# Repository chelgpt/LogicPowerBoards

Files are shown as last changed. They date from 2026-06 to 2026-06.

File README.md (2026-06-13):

# LogicPowerBoards

KiCad/KiCanvas workspace for the Docreate 002 modernization boards.

This repository is prepared for browser-based review through GitHub Pages + KiCanvas.

## Boards

- PowerBoard: 24V input, 5V / 20A isolated DC-DC board based on Mornsun URF2405QB-100WR3.
- LogicBoard: 24V input, 12V / 6W isolated DC-DC board based on Mornsun URB2412ZP-6WR3.

## Viewer

After enabling GitHub Pages from `main` / `docs`, open:

- `https://chelgpt.github.io/LogicPowerBoards/power.html`
- `https://chelgpt.github.io/LogicPowerBoards/logic.html`

Status: initial AI-assisted clean starter, not yet production-approved. Final manufacturing requires datasheet pinout verification, ERC/DRC, Gerber review, and ideally human EE review.

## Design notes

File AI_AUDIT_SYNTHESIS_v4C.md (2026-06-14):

# AI audit synthesis v4C

## Adopted facts

1. PowerBoard URF pin map: 1 +Vin, 2 Ctrl, 3 -Vin, 4 0V, 5 Sense-, 6 Trim, 7 Sense+, 8 +Vo.
2. PowerBoard URF drill sizes updated: 1.5mm for pins 1 2 3 5 6 7; 2.0mm for pins 4 8.
3. LogicBoard URB footprint changed from DIP8 placeholder to DIP24-grid footprint.
4. LogicBoard URB populated pins: 2 3 GND, 11 NC, 14 +Vo, 16 0V, 22 23 Vin.
5. LogicBoard capacitors updated to 100uF input bulk, 1uF input HF, 10uF output bulk, 100nF output HF.
6. PowerBoard precharge value is still TBD because it depends on C_bank, ESR, charge current and duty cycle.
7. PowerBoard TVS is now a selectable footprint, not a final installed value.
8. Output connector is marked as 30A-class target.
9. KiCad ERC, DRC, Gerber export and independent Gerber viewer check remain mandatory.

## Current verdict

LogicBoard is now a corrected v4C engineering candidate. PowerBoard is mechanically corrected and architecturally improved, but requires precharge and thermal closure before fab release.

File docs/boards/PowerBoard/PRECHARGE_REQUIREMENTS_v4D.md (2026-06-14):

# PowerBoard precharge requirements v4D

## Hard fact

The PowerBoard is not allowed to connect a large capacitive bank directly to the 5V output as if it were a normal output capacitor.

## Required input data

Before finalizing R_LIMIT or bypass parts, collect:

- C_bank in farads.
- Bank ESR in ohms.
- Initial voltage range.
- Target voltage.
- Allowed charge current.
- Required charge time.
- Charge repetition rate.
- Ambient temperature.
- Airflow or heatsink conditions.
- Whether the bank remains connected during normal 20A load operation.

## Sizing equations

- Peak current through resistor: I_peak = V_source / (R_LIMIT + ESR_bank + ESR_path)
- Stored energy in bank: E_bank = 0.5 * C_bank * V_target^2
- Resistor initial power: P0 = I_peak^2 * R_LIMIT
- RC time constant: tau = R_LIMIT * C_bank
- Approximate voltage after time t: Vc = V_source * (1 - exp(-t / tau))

## Topology decision

For private prototype use, keep two modes:

1. Safe test mode: R_LIMIT installed, bypass open.
2. Normal mode: R_LIMIT precharges first, then relay or MOSFET bypass shorts R_LIMIT after voltage delta is small.

## PCB implication

- R_LIMIT footprint is only a placeholder until energy and pulse rating are selected.
- J_BYP is intended for external relay or MOSFET bypass wiring.
- Do not install permanent zero-ohm bypass for first power-up.
- Add a bench procedure label: precharge first, bypass second.

## Remaining decision

The PCB cannot be called final until C_bank and I_charge are known.

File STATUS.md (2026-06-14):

# Project status

## Current version

v4M BOM and production gate pass.

## What changed in v4K

- PowerBoard PCB includes M3 mounting holes.
- PowerBoard PCB includes testpoints: TP_VIN, TP_GNDIN, TP_5V, TP_0V, TP_TRIM, TP_S+, TP_S-.
- PowerBoard silkscreen includes stronger guards: no-copper-under-module, remote-sense warning, precharge-first warning, input/output labels.
- LogicBoard PCB includes M3 mounting holes.
- LogicBoard PCB includes testpoints: TP1_24V, TP2_GND, TP3_12V, TP4_0V.
- Validator requires v4K testpoints, mounting holes and board marks.
- Added FAB_READINESS_SCORECARD_v4K.md.

## What changed in v4L

- Added ENGINEERING_FREEZE_v4L.md.
- Stopped speculative layout churn until CI logs, generated Gerbers, official footprint coordinates or real PowerBoard load data are available.

## What changed in v4M

- Updated PowerBoard_BOM.csv to match the v4K PCB state and current engineering decisions.
- Updated LogicBoard_BOM.csv to match the v4K PCB state and reject the stale DIP8 assumption.
- Added BOM_AUDIT_v4M.md to reconcile the uploaded BOM/TZ with the current design.
- Added ASSEMBLY_AND_BRINGUP_v4M.md.
- Added PRODUCTION_GATE_v4M.md.
- Fixed validate_repo.py version matcher so v4L/v4M and later statuses do not break CI.

## Current confidence

- LogicBoard: 89/100 as PCB architecture before automated ERC/DRC. Close to private prototype candidate after clean ERC/DRC and footprint-coordinate check.
- PowerBoard: 78/100 as PCB architecture before automated ERC/DRC and precharge closure. Not blind-order production-ready until real capacitive-bank/precharge data are closed.

## Next objective

Continue toward validation output, not cosmetic layout churn:

1. Get text-validation to pass.
2. Run or inspect heavy KiCad ERC/DRC/Gerber workflow.
3. Fix actual reported errors.
4. Produce reviewed fabrication package.

## Hard warning

v4M improves BOM/assembly/readiness closure but is still not a production release. The remaining blockers are validation outputs and PowerBoard load/precharge data.

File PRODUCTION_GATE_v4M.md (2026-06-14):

# Production gate v4M

## Gate result today

- LogicBoard: engineering prototype candidate, not final production release until ERC/DRC/Gerber pass.
- PowerBoard: engineering candidate, blocked by supercap/precharge/load data and ERC/DRC/Gerber pass.

## What can be considered ready

The repository is ready for automated validation and fabrication package generation attempts.

## What is not ready

The repository is not ready for blind PCB factory order.

## LogicBoard release path

LogicBoard can move to private prototype order after all of the following are true:

1. Text validation passes.
2. KiCad ERC passes.
3. KiCad DRC passes.
4. Gerber and drill files are generated.
5. Gerbers are reviewed.
6. Official URB2412ZP-6WR3 footprint coordinates are checked.

## PowerBoard release path

PowerBoard can move to private prototype order after all LogicBoard-style fabrication gates plus:

1. Real C_bank is known.
2. Real bank ESR is known.
3. Allowed charge current is known.
4. R_LIMIT value and pulse rating are selected.
5. Bypass relay/MOSFET strategy is selected.
6. Output connector part number and current rating are selected.
7. Thermal behavior is acceptable in bench test.

## Decision matrix

| Condition | LogicBoard | PowerBoard |
|---|---:|---:|
| Schematic exists | yes | yes |
| PCB exists | yes | yes |
| BOM current | yes | yes |
| Testpoints | yes | yes |
| Mounting holes | yes | yes |
| Text validator | present | present |
| ERC result | pending | pending |
| DRC result | pending | pending |
| Gerbers | pending | pending |
| Official footprint coordinates | pending | pending |
| Load/precharge closure | not needed | pending |

## Final instruction

Do not call this production-ready until pending rows are closed.

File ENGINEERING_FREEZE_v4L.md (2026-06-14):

# Engineering freeze v4L

## Decision

The current repository state is frozen as an engineering candidate until automated validation results or real PowerBoard load data are available.

This is not a prompt for more speculative layout iterations. Further edits without CI feedback would increase churn and may reduce quality.

## Current board scores

- LogicBoard: 88/100 as PCB architecture before automated ERC/DRC.
- PowerBoard: 76/100 as PCB architecture before automated ERC/DRC and precharge closure.

## What is already closed

- Browser KiCanvas review workflow.
- Main page with board tabs and engineering document links.
- PowerBoard and LogicBoard PCB text files.
- Component-level schematic files.
- Netlist lock.
- DRC/net-class intent.
- Release gates.
- Fabrication package manifest.
- Lightweight text-validation workflow.
- Manual heavy KiCad ERC/DRC/Gerber workflow.
- PowerBoard testpoints and mounting holes.
- LogicBoard testpoints and mounting holes.
- Stronger silkscreen labels and bring-up warnings.

## Stop condition

Stop editing the repo now unless one of the following inputs appears:

1. GitHub Actions text-validation failure log.
2. GitHub Actions KiCad ERC/DRC/export failure log.
3. Generated fabrication-output artifact.
4. Official Mornsun footprint coordinate file or drawing extraction.
5. Real PowerBoard capacitive-bank data: capacitance, ESR, allowed charge current, duty cycle.
6. Selected 20A output connector part number.

## Honest production verdict

LogicBoard is close to private prototype readiness, but still needs automated ERC/DRC and footprint-coordinate validation.

PowerBoard is not production-ready for a blind order because the real load is a capacitive bank. Precharge and thermal/current behavior must be closed before calling it production-ready.

## Final no-order rule

Do not order boards until:

- text-validation passes,
- ERC passes,
- DRC passes,
- Gerbers and drills are generated,
- Gerbers are reviewed,
- official footprint coordinates are verified,
- PowerBoard precharge/load assumptions are closed or explicitly accepted for prototype risk.

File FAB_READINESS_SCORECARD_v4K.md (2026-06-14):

# Fab readiness scorecard v4K

## Scoring model

100 means ready to order private-use prototype boards from generated Gerbers after clean ERC/DRC and final visual review.

## LogicBoard

Current score: 88/100 before automated ERC/DRC.

Closed in v4K:

- Mounting holes added to PCB.
- Testpoints added: TP1_24V, TP2_GND, TP3_12V, TP4_0V.
- Polarity and board-version silkscreen strengthened.
- Validator updated to require LogicBoard testpoints, mounting holes and v4K mark.

Still open:

- Official footprint coordinate check against Mornsun mechanical drawing.
- KiCad ERC result.
- KiCad DRC result.
- Gerber/drill artifact review.

## PowerBoard

Current score: 76/100 before automated ERC/DRC and precharge closure.

Closed in v4K:

- Mounting holes added to PCB.
- Testpoints added: TP_VIN, TP_GNDIN, TP_5V, TP_0V, TP_TRIM, TP_S+, TP_S-.
- Silkscreen guards added: no copper under module, remote sense warning, precharge-first warning, input/output domain labels.
- Validator updated to require PowerBoard testpoints, mounting holes and v4K mark.

Still open:

- Official footprint coordinate check against Mornsun mechanical drawing.
- KiCad ERC result.
- KiCad DRC result.
- Gerber/drill artifact review.
- Real supercap data: capacitance, ESR, allowed charge current, cycle rate.
- R_LIMIT value and pulse rating.
- Bypass relay/MOSFET part selection and timing.
- Thermal check for 20A operation and module cooling.

## Next gate

v4L should focus on official-footprint coordinate closure and CI feedback. If automated text validation passes, run the manual KiCad export workflow and fix the first real ERC/DRC/export errors.

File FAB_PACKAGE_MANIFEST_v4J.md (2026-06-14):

# Fab package manifest v4J

## Purpose

Defines the expected contents of a fabrication package once the manual KiCad CI export succeeds.

## Expected CI artifact

Artifact name: fabrication-output.

## Expected folders

- fabrication_output/reports
- fabrication_output/PowerBoard/gerbers
- fabrication_output/LogicBoard/gerbers

## Required report files

- reports/kicad_cli_version.txt
- reports/PowerBoard_erc.rpt
- reports/LogicBoard_erc.rpt
- reports/PowerBoard_drc.rpt
- reports/LogicBoard_drc.rpt

## Required board outputs

For each board:

- Top copper Gerber.
- Bottom copper Gerber.
- Top soldermask Gerber.
- Bottom soldermask Gerber.
- Top silkscreen Gerber.
- Bottom silkscreen Gerber if exported.
- Edge cuts / board outline Gerber.
- Excellon drill file.
- Drill map if exported.

## Factory order parameters

- PCB type: two-layer FR-4.
- Board thickness: 1.6mm.
- Copper: 2oz.
- Minimum clearance: 0.30mm or better.
- Surface finish: ENIG preferred; lead-free HASL acceptable for private prototype if budget constrained.
- Soldermask: green preferred for lowest manufacturing risk.
- Electrical test: yes.
- Controlled impedance: no.
- Castellated holes: no.
- Blind/buried vias: no.
- Panelization: no unless manufacturer requires it.

## Final no-order conditions

Do not order if any of the following is true:

- ERC report contains unresolved errors.
- DRC report contains unresolved errors.
- Gerber viewer shows broken outline.
- Drill file is missing.
- Input/output polarity marks are hidden or ambiguous.
- PowerBoard output connector current rating is still unknown.
- PowerBoard precharge sizing is still unknown for the real capacitive bank.
- Official Mornsun footprint coordinate check is not done.

## Private-use prototype order condition

The project may only move to private-use prototype order after:

1. Text validation passes.
2. KiCad ERC passes.
3. KiCad DRC passes.
4. Gerbers and drill files are generated.
5. Gerbers are visually reviewed.
6. Known PowerBoard precharge risks are accepted or closed.

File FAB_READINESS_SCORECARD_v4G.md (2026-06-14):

# Fab readiness scorecard v4G

## Scoring model

100 means ready to order private-use prototype boards from generated Gerbers after final visual review. v4G adds automated validation/export pipeline, but final score depends on CI results.

## LogicBoard

Current score: 84/100 before CI results.

Closed:

- Corrected away from wrong DIP8 placeholder.
- Uses URB ZP DIP24 populated-pin map in PCB.
- Input/output capacitor values aligned to audit consensus.
- Net classes and 0.30mm clearance configured in project file.
- DRC rules and release gates documented.
- Browser review workflow works.
- v4F component-level schematic generated from NETLIST_LOCK_v4E.
- v4G CI pipeline added for text validation, KiCad ERC, DRC, Gerber and drill export.

Remaining:

- GitHub Actions text validation result.
- KiCad ERC result.
- KiCad DRC result.
- Gerber/drill artifact review.
- Exact official Mornsun footprint coordinate check.

## PowerBoard

Current score: 70/100 before CI results.

Closed:

- URF pin drill sizes corrected.
- Output terminal enlarged to 30A-class target footprint.
- Input fuse candidate corrected to 10A slow/link class.
- Precharge block separated from final value selection.
- External bypass header added for relay or MOSFET bypass concept.
- TVS changed to selectable footprint rather than final fixed assumption.
- Net classes configured: power input, power output 20A, sense/trim/ctrl.
- DRC rules and precharge requirements documented.
- v4F component-level schematic generated from NETLIST_LOCK_v4E.
- v4G CI pipeline added for text validation, KiCad ERC, DRC, Gerber and drill export.

Remaining:

- GitHub Actions text validation result.
- KiCad ERC result.
- KiCad DRC result.
- Gerber/drill artifact review.
- Exact official Mornsun footprint coordinate check.
- Real supercap data: capacitance, ESR, allowed charge current, cycle rate.
- R_LIMIT value and pulse rating.
- Bypass relay/MOSFET part selection and timing.
- Thermal check for 20A operation and module cooling.

## Next gate

v4H must read the GitHub Actions result. If text validation fails, fix repository-level contradictions. If KiCad ERC/DRC/export fails, fix the exact reported syntax/electrical/manufacturing errors. If CI passes, download fabrication-output and prepare a release package review.

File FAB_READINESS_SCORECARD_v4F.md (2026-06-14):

# Fab readiness scorecard v4F

## Scoring model

100 means ready to generate Gerbers for a private prototype order after final visual review and automated KiCad ERC/DRC results.

## LogicBoard

Current score: 82/100.

Closed:

- Corrected away from wrong DIP8 placeholder.
- Uses URB ZP DIP24 populated-pin map in PCB.
- Input/output capacitor values aligned to audit consensus.
- Net classes and 0.30mm clearance configured in project file.
- DRC rules and release gates documented.
- Browser review workflow works.
- v4F component-level schematic generated from NETLIST_LOCK_v4E.

Remaining:

- Exact official Mornsun footprint coordinate check.
- Automated KiCad ERC output.
- Automated KiCad DRC output.
- Gerber and drill export.
- Independent Gerber viewer check.

## PowerBoard

Current score: 68/100.

Closed:

- URF pin drill sizes corrected.
- Output terminal enlarged to 30A-class target footprint.
- Input fuse candidate corrected to 10A slow/link class.
- Precharge block separated from final value selection.
- External bypass header added for relay or MOSFET bypass concept.
- TVS changed to selectable footprint rather than final fixed assumption.
- Net classes configured: power input, power output 20A, sense/trim/ctrl.
- DRC rules and precharge requirements documented.
- v4F component-level schematic generated from NETLIST_LOCK_v4E.

Remaining:

- Exact official Mornsun footprint coordinate check.
- Real supercap data: capacitance, ESR, allowed charge current, cycle rate.
- R_LIMIT value and pulse rating.
- Bypass relay/MOSFET part selection and timing.
- Thermal check for 20A operation and module cooling.
- Automated KiCad ERC output.
- Automated KiCad DRC output.
- Gerber and drill export.
- Independent Gerber viewer check.

## Next gate

v4G should add an automated validation/export path. Preferred route: GitHub Actions job using kicad-cli to run ERC, DRC and plot fabrication outputs when KiCad CLI is available in the runner/container.

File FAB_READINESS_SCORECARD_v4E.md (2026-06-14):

# Fab readiness scorecard v4E

## Scoring model

100 means ready to generate Gerbers for a private prototype order after final visual review. Current score is lower because the project still lacks a verified real schematic and automated KiCad DRC/ERC results.

## LogicBoard

Current score: 76/100.

Closed:

- Corrected away from wrong DIP8 placeholder.
- Uses URB ZP DIP24 populated-pin map in PCB.
- Input/output capacitor values aligned to audit consensus.
- Net classes and 0.30mm clearance configured in project file.
- DRC rules and release gates documented.
- Browser review workflow works.

Remaining:

- Exact official Mornsun footprint coordinate check.
- Real schematic file with symbols/wires matching NETLIST_LOCK_v4E.
- KiCad ERC output.
- KiCad DRC output.
- Gerber and drill export.
- Independent Gerber viewer check.

## PowerBoard

Current score: 62/100.

Closed:

- URF pin drill sizes corrected.
- Output terminal enlarged to 30A-class target footprint.
- Input fuse candidate corrected to 10A slow/link class.
- Precharge block separated from final value selection.
- External bypass header added for relay or MOSFET bypass concept.
- TVS changed to selectable footprint rather than final wrong assumption.
- Net classes configured: power input, power output 20A, sense/trim/ctrl.
- DRC rules and precharge requirements documented.

Remaining:

- Exact official Mornsun footprint coordinate check.
- Real schematic file with symbols/wires matching NETLIST_LOCK_v4E.
- Real supercap data: capacitance, ESR, allowed charge current, cycle rate.
- R_LIMIT value and pulse rating.
- Bypass relay/MOSFET part selection and timing.
- Thermal check for 20A operation and module cooling.
- KiCad ERC output.
- KiCad DRC output.
- Gerber and drill export.
- Independent Gerber viewer check.

## Next gate

v4F should generate real KiCad schematics from NETLIST_LOCK_v4E and keep KiCanvas viewer stable.

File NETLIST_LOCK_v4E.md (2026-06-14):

# NETLIST LOCK v4E

This document is the locked electrical connectivity reference for the current engineering candidate. PCB and future schematic must match this file.

## PowerBoard nets

### VIN_24V

- J_IN pin 1
- F1 pin 1
- TP_VIN if populated

### GND_IN

- J_IN pin 2
- U1 pin 3 (-Vin)
- C_IN pin 2
- C_IN_HF pin 2
- J_CTRL pin 2
- TP_GNDIN if populated

### VIN_AFTER_F1

- F1 pin 2
- R_LIMIT pin 1
- J_BYP pin 1

### VIN_TO_MODULE

- R_LIMIT pin 2
- J_BYP pin 2
- U1 pin 1 (+Vin)
- C_IN pin 1
- C_IN_HF pin 1

### CTRL

- U1 pin 2
- J_CTRL pin 1

### OUT_0V

- U1 pin 4
- J_OUT pin 2
- C_OUT pin 2
- C_OUT_HF pin 2
- JP_S- pin 2
- D_TVS pin 2 if installed
- TP_0V if populated

### SENSE_N

- U1 pin 5
- JP_S- pin 1
- RV1 pin 1 if trim is populated
- TP_S- if populated

### TRIM

- U1 pin 6
- RV1 pin 2 if trim is populated
- TP_TRIM if populated

### SENSE_P

- U1 pin 7
- JP_S+ pin 1
- RV1 pin 3 if trim is populated
- TP_S+ if populated

### OUT_5V

- U1 pin 8
- J_OUT pin 1
- C_OUT pin 1
- C_OUT_HF pin 1
- JP_S+ pin 2
- D_TVS pin 1 if installed
- TP_5V if populated

## LogicBoard nets

### VIN_24V

- J1 pin 1
- U1 pins 22 and 23
- C1 pin 1
- C2 pin 1
- TP1_24V if populated

### GND_IN

- J1 pin 2
- U1 pins 2 and 3
- C1 pin 2
- C2 pin 2
- TP2_GND if populated

### OUT_12V

- U1 pin 14
- J2 pin 1
- J3 pin 1
- C3 pin 1
- C4 pin 1
- TP3_12V if populated

### GND_OUT

- U1 pin 16
- J2 pin 2
- J3 pin 2
- C3 pin 2
- C4 pin 2
- TP4_0V if populated

### NC / no pin

- U1 pin 11: NC, no copper connection.
- U1 pin 9: physically absent, no pad.

## Locked manufacturing assumptions

- Board size: 50 x 100mm.
- Layers: 2 copper layers.
- Copper: 2oz.
- General clearance: 0.30mm.
- PowerBoard output paths: copper pours or 10-15mm equivalent width.
- PowerBoard sense lines: Kelvin-style, separate from high-current copper.

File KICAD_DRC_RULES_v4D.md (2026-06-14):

# KiCad DRC rules v4D

## Board stack

- Layers: 2 copper layers.
- Copper weight: 2oz.
- Board thickness: 1.6mm unless enclosure demands otherwise.
- Board outline: 50 x 100mm.

## Global rules

- Minimum clearance: 0.30mm.
- Minimum track width for signal nets: 0.25mm.
- Preferred signal width: 0.35mm.
- Minimum via drill: avoid below 0.30mm unless fab selected.
- Annular ring: use fab default or larger.

## PowerBoard net classes

### Input power

Nets: VIN_24V, GND_IN, VIN_AFTER_F1, VIN_TO_MODULE.

- Preferred routing: pours or wide traces.
- Minimum width if trace-only: 5mm for high-current sections.
- Keep routing short between J_IN, F1, R_LIMIT, U1.

### Output power

Nets: OUT_5V, OUT_0V.

- Preferred routing: copper pours, not narrow traces.
- Minimum equivalent copper width: 10-15mm.
- Thermal relief: off for module output pins and output terminal pads.
- If top and bottom copper share current, use via stitching.
- Avoid bottlenecks at terminal pads and module pins.

### Sense and trim

Nets: SENSE_P, SENSE_N, TRIM.

- Width: 0.25-0.35mm.
- Route separately from high-current copper.
- Kelvin route sense lines to output connector or close fallback jumpers.
- Do not allow floating sense nets.

### Ctrl

Net: CTRL.

- Reference to GND_IN only.
- Keep away from OUT_0V assumptions.

## LogicBoard net classes

- VIN_24V and GND_IN: 0.8-1.2mm preferred.
- OUT_12V and GND_OUT: 0.8-1.2mm preferred.
- Keep input and output domains separated.

## Required DRC review points

- Board outline closed.
- No unconnected pads unless explicitly NC.
- No copper crossing isolation boundary unnecessarily.
- No thermal relief on high-current pads.
- Drill sizes match module pins.
- Silkscreen does not overlap pads.
- Polarity marks visible after assembly.

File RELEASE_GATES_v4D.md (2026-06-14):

# Release gates v4D

## Purpose

This file defines the gates that must be closed before any factory order.

## Gate A - source truth

- Use official Mornsun datasheet for URF2405QB-100WR3.
- Use official Mornsun datasheet for URB2412ZP-6WR3.
- Import or manually match official mechanical footprints.
- Do not use generic DIP8 for URB ZP.
- Do not use undersized drills for URF QB.

## Gate B - KiCad integrity

- Real schematic must exist, not text-only placeholder.
- ERC must pass or every warning must be documented.
- PCB footprints must be linked to schematic references.
- PCB net names must match schematic net names.
- DRC minimum clearance: 0.30mm or tighter only if fab selected and accepted.
- Board outline: 50 x 100mm.
- Copper: two layers, 2oz.

## Gate C - PowerBoard electrical closure

- URF pin map: 1 +Vin, 2 Ctrl, 3 -Vin, 4 0V, 5 Sense-, 6 Trim, 7 Sense+, 8 +Vo.
- Sense+ must connect to +Vo when remote sense is not wired.
- Sense- must connect to 0V when remote sense is not wired.
- Ctrl is referenced to input GND.
- Ctrl open equals ON; Ctrl short to input GND equals OFF.
- Trim must be NC or populated only after bench target is defined.
- Input fuse candidate: 10A slow or validated equivalent.
- Output connector: continuous 20A capable, preferably 25-30A class.
- Output direct capacitive load must stay below module limit unless isolated by precharge stage.
- Precharge value and bypass timing must be calculated from real load data.

## Gate D - LogicBoard electrical closure

- URB ZP pin map: 2 and 3 GND_IN; 11 NC; 14 OUT_12V; 16 GND_OUT; 22 and 23 VIN_24V.
- Pin 9 absent, no pad required.
- No trim, sense or ctrl assumptions unless confirmed by exact datasheet revision.
- Input bulk capacitor 100uF/50V plus HF cap close to input pins.
- Output bulk capacitor within module capacitive load limit.

## Gate E - fabrication package

- Gerber top copper.
- Gerber bottom copper.
- Gerber solder masks.
- Gerber silkscreens.
- Edge cuts / board outline.
- Excellon drill file.
- Drill map.
- Fab notes.
- BOM.
- Optional pick/place if assembly is outsourced.

## Gate F - pre-power bench checks

- Bare PCB continuity test.
- Input to output isolation resistance check.
- No short between VIN_24V and GND_IN.
- No short between output rails.
- No short between primary and secondary domains.
- First power-up from current-limited bench supply.
- No final load on first power-up.

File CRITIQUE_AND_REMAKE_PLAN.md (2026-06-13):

# LogicPowerBoards critique and remake plan

Status: v3 is a browser-review starter only. It is intentionally not a manufacturing release.

## Hard blockers in current v3

1. **Synthetic footprints.** The Mornsun footprints are approximate placeholders. They must be replaced or verified against official Mornsun footprint/mechanical drawings before production.
2. **Schematic is placeholder text.** ERC cannot be meaningful until the real circuit is captured as a real KiCad schematic with symbols, nets, power flags and no-connects.
3. **PowerBoard pinout is not yet authoritative.** Current pin mapping follows the earlier AI draft/TZ intent but is not validated against the official datasheet and official footprint.
4. **No final copper topology.** The 5V/20A path needs heavy copper pours, short current loops, large pads, current-sharing vias and no thermal relief on high-current pads.
5. **Supercapacitor inrush strategy is unresolved.** R_LIMIT footprint exists conceptually, but the final design must choose either a power resistor strategy or MOSFET/relay bypass strategy with thermal/pulse rating.
6. **Sense/trim/control nets need fail-safe treatment.** Sense fallback jumpers, trace routing, silkscreen warnings and default solder state need to be explicit.
7. **No manufacturing outputs.** Gerbers, Excellon drill, drill map, fab drawing and assembly/BOM outputs are not released yet.
8. **No independent DRC/ERC pass.** KiCanvas display is only a visual browser check, not validation.

## What “90-100% production ready” means here

I will treat the target as **production-candidate v1**, not a legal/engineering certification.
A board can be called production-candidate only after:

- official Mornsun datasheets and footprints are checked,
- real KiCad schematic exists,
- PCB nets match schematic,
- DRC/ERC pass,
- Gerbers/Excellon export correctly,
- independent Gerber viewer check passes,
- power/current/thermal assumptions are documented,
- final human EE review is done before ordering.

## Remake strategy

### Phase 1 — Freeze requirements and authoritative sources

- Lock board size: 50 x 100 mm, 2 layers, FR-4, 2 oz copper.
- Lock clearance: >= 0.30 mm general.
- Lock isolation: 3-5 mm between input and isolated output domains.
- Use official Mornsun datasheet + symbol + footprint downloads as source of truth.
- Keep current GitHub Pages/KiCanvas flow for every iteration.

### Phase 2 — Rebuild schematics

PowerBoard schematic blocks:

- 24V input terminal.
- Optional 20A fuse.
- Inrush/current-limit block.
- URF2405QB-100WR3 module.
- Input bulk + ceramic capacitor.
- Output bulk + ceramic capacitor.
- TVS SMDJ7.0A across 5V output.
- Ctrl header: open = ON, short to -Vin = OFF.
- Sense fallback: Sense+ to +Vo, Sense- to 0V.
- Trim network: 3296W trimpot + 47k resistors.
- Test points: +Vin, -Vin, +Vo, 0V, Trim, Sense+, Sense-.

LogicBoard schematic blocks:

- 24V input terminal.
- URB2412ZP-6WR3 module.
- Input 10uF + 0.1uF.
- Output 22uF + 0.1uF.
- 12V output terminal.
- Fan/Noctua output terminal if required by actual harness.
- Test points: +24V, GND, +12V, 0V.

### Phase 3 — Rebuild board placement

PowerBoard placement principles:

- Input connector/fuse/current-limit near input edge.
- URF module central, with input side and output side clearly separated.
- 5V output connector and supercap-facing copper close to module output pins.
- Bulk capacitors close to their module side.
- TVS directly across +5V/0V near output connector.
- Sense jumpers and testpoints accessible but away from high-current switching loops.
- Trim trimpot accessible from board edge or top side.
- Silkscreen warnings large and unambiguous.

LogicBoard placement principles:

- Input connector near input side, output/fan connectors near output side.
- Small converter central.
- Capacitors adjacent to corresponding pins.
- Test points accessible.
- Clear isolated input/output separation.

### Phase 4 — Copper and routing

PowerBoard:

- Bottom-heavy copper pours for VIN, GND_IN, +5V, 0V.
- Output +5V and 0V should use large pours/planes, not narrow traces.
- Target 10-15 mm equivalent copper width for 20A paths or solid copper zones.
- Use via stitching where top/bottom copper share current.
- Disable thermal relief on heavy-current pads.
- Keep sense traces thin, separate and Kelvin-routed to output connector/load side.

LogicBoard:

- Moderate trace width for 0.5A 12V output.
- Keep input and output isolated domains separated.
- Avoid unnecessary copper under isolation boundary if datasheet recommends it.

### Phase 5 — Release package

- KiCad files.
- BOM CSV.
- POS CSV if assembly is needed.
- Gerbers.
- Excellon drill.
- Fab notes.
- README release notes.
- Known assumptions list.

## Immediate v4 tasks

1. Replace placeholder schematics with real circuit structure.
2. Upgrade PCB files to show all required functional blocks in KiCanvas.
3. Add visual net/domain labels and isolation boundary.
4. Add missing required PowerBoard blocks: fuse, inrush limiter, TVS, caps, ctrl, sense fallback, trim, testpoints.
5. Add missing LogicBoard blocks: output/fan connector, caps, testpoints.
6. Keep all modifications small and reviewable through GitHub Pages.

## Red flags that must not be ignored

- If official Mornsun footprint disagrees with current pad placement, current footprint must be discarded.
- If datasheet recommends different capacitance/ESR limits, BOM must be adjusted.
- If supercap bank capacitance is large, simple R_LIMIT may be thermally inadequate; use controlled precharge/bypass instead.
- 20A terminal blocks and pads must be matched to real wire gauge and connector current rating.
- 2 oz copper helps, but 20A still requires serious copper geometry and thermal checks.

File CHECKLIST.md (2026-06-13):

# Production checklist

Current repository state: **starter/review layout**, not a manufacturing release.

## Must verify before Gerbers

- Verify official Mornsun pinouts and recommended external circuits for URF2405QB-100WR3 and URB2412ZP-6WR3.
- Replace synthetic footprints with official/verified footprints or measured drawings.
- PowerBoard: verify Ctrl logic: open = ON, short Ctrl to -Vin = OFF.
- PowerBoard: verify Sense+ and Sense- fallback jumpers and avoid floating sense nets.
- PowerBoard: add/validate TVS SMDJ7.0A, inrush limiter/bypass strategy, fuse footprint, trim network, test points.
- Route heavy copper: 2 oz, 10–15 mm equivalent output current paths, 5–8 mm input paths, via stitching where needed.
- Maintain 0.30 mm minimum clearance and 3–5 mm input/output isolation.
- Run KiCad ERC/DRC.
- Export and review Gerbers/Excellon in independent Gerber viewer.
- Human EE review before ordering, especially due to 5V/20A and supercapacitor charging.

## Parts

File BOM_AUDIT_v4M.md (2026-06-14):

# BOM audit v4M

## Purpose

This file reconciles the original uploaded BOM/TZ with the current engineering design.

## Important corrections

### LogicBoard module footprint

Original BOM described URB2412ZP-6WR3 as DIP-8 with pins 1,2,5,7. That assumption was rejected after audit. Current design uses URB ZP DIP24-grid populated pins:

- 2,3 = GND_IN
- 11 = NC
- 14 = OUT_12V
- 16 = GND_OUT
- 22,23 = VIN_24V
- pin 9 absent

### LogicBoard capacitors

Original TZ said 10uF input and 22uF output. Current audit-updated design uses:

- C1 = 100uF / 50V input bulk
- C2 = 1uF / 50V input ceramic
- C3 = 10uF / 25V output bulk
- C4 = 100nF output ceramic

This is intentionally different from the early BOM because the early BOM was tied to the rejected DIP8/placeholder phase.

### PowerBoard input protection

Original TZ listed optional 20A fuse. Current design uses input-side 10A slow fuse or link candidate because the module is 100W at 24V nominal, so input current is not 20A continuous. Final fuse still depends on inrush and source behavior.

### PowerBoard TVS

Original TZ listed SMDJ7.0A. Current design leaves TVS as SELECT/DNP default. Reason: a TVS across the 5V output is not a complete supercap over-voltage protection strategy. Final OVP must be selected after real load and transient behavior are known.

### PowerBoard trim network

Original TZ requested 47k side resistors and 3296W trimmer. Current PCB has RV1 footprint and trim/sense nets but keeps trim effectively optional/DNP until the exact official Mornsun trim formula and target voltage range are confirmed. Default prototype path is nominal output with sense fallback closed and trim unpopulated unless bench testing requires adjustment.

### PowerBoard precharge

Original TZ requested R_LIMIT or bypass. Current design implements both:

- R_LIMIT footprint marked SIZE_BY_C_BANK
- J_BYP external relay/MOSFET bypass header

Final R_LIMIT value cannot be derived from BOM alone. Required data: capacitance, ESR, charge current, duty cycle, thermal environment.

## Current BOM files

- docs/boards/PowerBoard/PowerBoard_BOM.csv
- docs/boards/LogicBoard/LogicBoard_BOM.csv

These are the current working BOMs. The original uploaded BOM is historical input, not the current production BOM.

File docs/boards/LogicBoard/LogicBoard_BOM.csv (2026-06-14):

Reference | Qty | Value | Package | Notes
U1 | 1 | URB2412ZP-6WR3 | DIP24 grid TH | Populated pins 2 3 GND 11 NC 14 +Vo 16 0V 22 23 Vin; original DIP8 assumption rejected
J1 | 1 | 24V input terminal 2P | 5.08mm | Input from 24V rail
J2 | 1 | 12V output terminal 2P | 5.08mm | Output to logic rail
J3 | 1 | 12V fan output terminal 2P | 5.08mm | Optional fan output if harness requires it
C1 | 1 | 100uF 50V low ESR | THT radial | Input bulk capacitor per audit-updated design
C2 | 1 | 1uF 50V X7R | 1206 ceramic | Input HF capacitor close to U1
C3 | 1 | 10uF 25V low ESR | THT radial | Output bulk capacitor; stay within module capacitive-load limit
C4 | 1 | 100nF 25V | 1206 ceramic | Output HF capacitor close to U1
TP1_24V TP2_GND TP3_12V TP4_0V | 4 | Test points | 1mm pad | +24V GND +12V 0V bring-up points
H1 H2 | 2 | M3 mounting holes | NPTH 3.2mm | Mechanical mounting; keep metal hardware away from live copper

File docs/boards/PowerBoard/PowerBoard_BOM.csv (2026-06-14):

Reference | Qty | Value | Package | Notes
U1 | 1 | URF2405QB-100WR3 | quarter-brick through-hole | Official Mornsun footprint/pinout must be verified before ordering
J_IN | 1 | 24V input terminal 2P | 5.08mm or higher current rated | Use connector rated for actual input current and wire gauge
J_OUT | 1 | 5V 20A output terminal 2P | 30A-class high-current terminal | 20A continuous path requires connector datasheet and pad current validation
F1 | 1 | 10A slow fuse or 0R link | through-hole power footprint | Input-side candidate; final fuse based on real input current and inrush profile
R_LIMIT | 1 | SIZE_BY_C_BANK | high-pulse-power resistor footprint | Final value and pulse power depend on supercap C ESR charge current and duty cycle
J_BYP | 1 | External relay or MOSFET bypass header | 2P through-hole | Bypass R_LIMIT only after precharge; do not short for first power-up
C_IN | 1 | 220uF 63V low-ESR | THT radial | Place close to input pins
C_IN_HF | 1 | 10uF 50V X7R | 1206 ceramic | Matches current PCB marking; add 100nF in next footprint revision if EMC testing requires it
C_OUT | 1 | 470uF 25-35V low-ESR | THT radial | 35V preferred per original BOM; keep total direct output capacitance within module limit
C_OUT_HF | 1 | 100nF 50V | 1206 ceramic | Place close to output pins
D_TVS | 1 | TVS_SELECT DNP default | SMC/SMDJ footprint | Do not treat SMDJ7.0A as final supercap overvoltage protection without OVP strategy
J_CTRL | 1 | Ctrl jumper/header | 2.54mm 1x2 | Open=ON; short CTRL to GND_IN=OFF
RV1 | 1 | 3296W 10k DNP until trim target set | vertical trimmer | Trim optional; default private prototype can run nominal output with trim unpopulated
JP_S+ | 1 | Sense+ fallback solder jumper | 2-pad solder jumper | Close if remote sense not wired
JP_S- | 1 | Sense- fallback solder jumper | 2-pad solder jumper | Close if remote sense not wired
TP_VIN TP_GNDIN TP_5V TP_0V TP_TRIM TP_S+ TP_S- | 7 | Test points | 1mm loop/pad | For bring-up and verification
H1 H2 | 2 | M3 mounting holes | NPTH 3.2mm | Mechanical mounting; keep metal hardware away from live copper

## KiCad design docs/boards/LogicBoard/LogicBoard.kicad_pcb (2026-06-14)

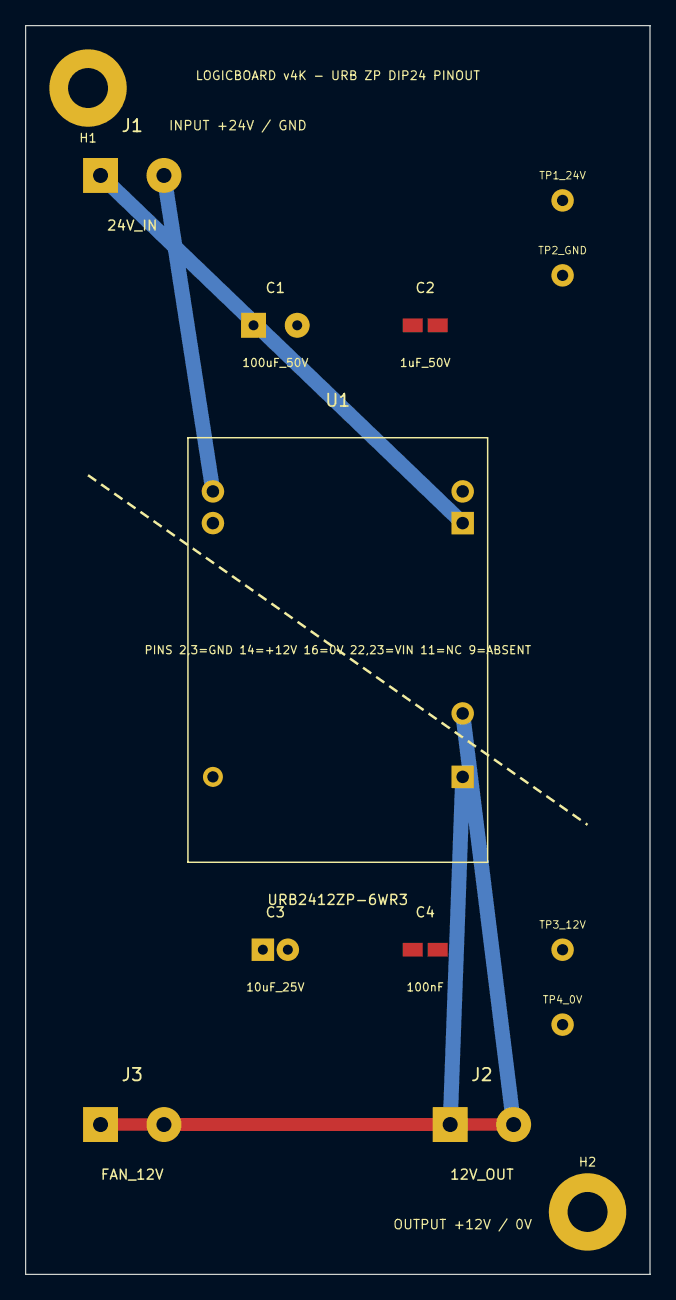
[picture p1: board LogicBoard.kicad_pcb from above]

Board: 2 copper layers, 50.0 x 100.0 mm, 14 parts (0 on the bottom side), 4 nets.

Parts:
C1: 100uF_50V; CP_Radial
C2: 1uF_50V; C1206
C3: 10uF_25V; CP_Radial
C4: 100nF; C1206
H1, H2: MountingHole_M3
J1: 24V_IN; Terminal_2P_5_08
J2: 12V_OUT; Terminal_2P_5_08
J3: FAN_12V; Terminal_2P_5_08
TP1_24V, TP2_GND, TP3_12V, TP4_0V: TP1mm
U1: URB2412ZP-6WR3; Mornsun_URB2412ZP_6WR3_DIP24

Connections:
GND_IN: C1.2, C2.2, J1.2, TP2_GND.1, U1.2, U1.3
GND_OUT: C3.2, C4.2, J2.2, J3.2, TP4_0V.1, U1.16
OUT_12V: C3.1, C4.1, J2.1, J3.1, TP3_12V.1, U1.14
VIN_24V: C1.1, C2.1, J1.1, TP1_24V.1, U1.22, U1.23

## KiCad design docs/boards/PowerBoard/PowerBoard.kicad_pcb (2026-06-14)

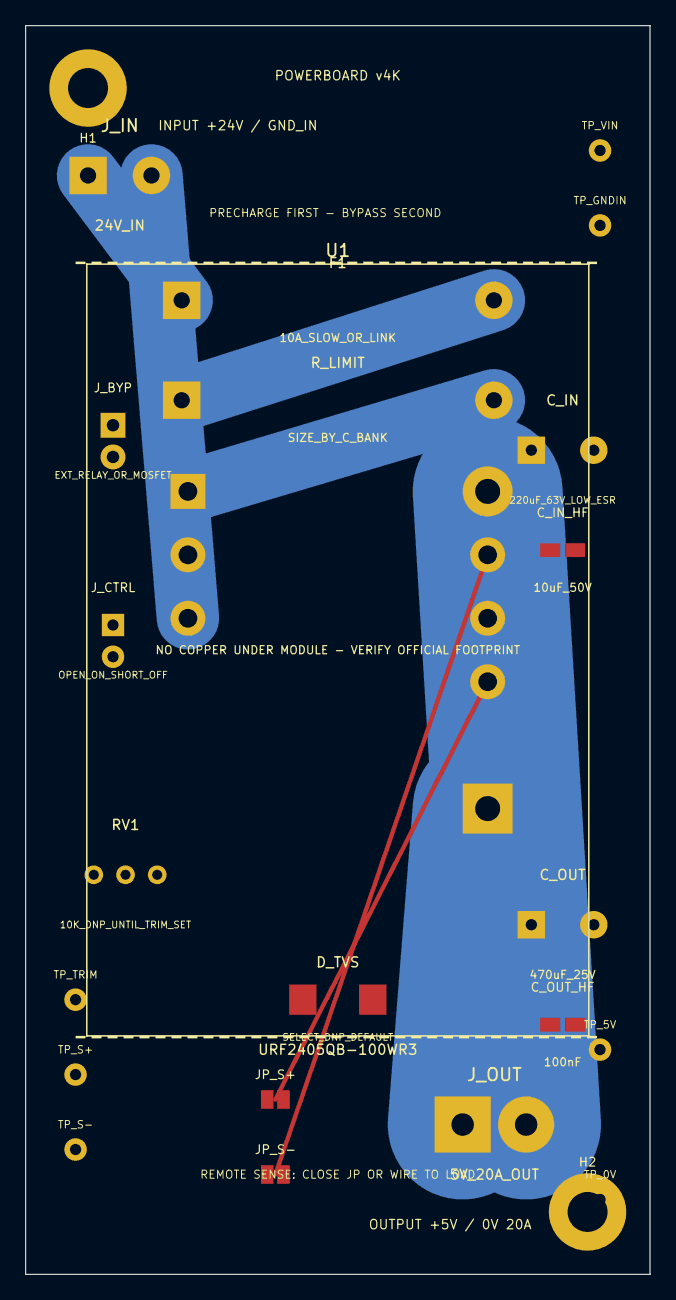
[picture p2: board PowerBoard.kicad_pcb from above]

Board: 2 copper layers, 50.0 x 100.0 mm, 24 parts (0 on the bottom side), 10 nets.

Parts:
C_IN: 220uF_63V_LOW_ESR; CP_Radial
C_IN_HF: 10uF_50V; C1206
C_OUT: 470uF_25V; CP_Radial
C_OUT_HF: 100nF; C1206
D_TVS: SELECT_DNP_DEFAULT; TVS_SMC_SELECT
F1: 10A_SLOW_OR_LINK; Fuse_or_Link_10A
H1, H2: MountingHole_M3
JP_S+: Sense_Jumper_Plus
JP_S-: Sense_Jumper_Minus
J_BYP: EXT_RELAY_OR_MOSFET; External_Bypass_Header
J_CTRL: OPEN_ON_SHORT_OFF; Header_1x2
J_IN: 24V_IN; Terminal_IN_2P
J_OUT: 5V_20A_OUT; Terminal_OUT_2P_30A
RV1: 10K_DNP_UNTIL_TRIM_SET; Trim_3296W
R_LIMIT: SIZE_BY_C_BANK; Precharge_R
TP_0V, TP_5V: TP1mm
TP_GNDIN: TP1mm
TP_S+: TP1mm
TP_S-: TP1mm
TP_TRIM: TP1mm
TP_VIN: TP1mm
U1: URF2405QB-100WR3; Mornsun_URF2405QB_100WR3_QB

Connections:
CTRL: J_CTRL.1, U1.2
GND_IN: C_IN.2, C_IN_HF.2, J_CTRL.2, J_IN.2, TP_GNDIN.1, U1.3
OUT_0V: C_OUT.2, C_OUT_HF.2, D_TVS.2, JP_S-.2, J_OUT.2, TP_0V.1, U1.4
OUT_5V: C_OUT.1, C_OUT_HF.1, D_TVS.1, JP_S+.2, J_OUT.1, TP_5V.1, U1.8
SENSE_N: JP_S-.1, RV1.1, TP_S-.1, U1.5
SENSE_P: JP_S+.1, RV1.3, TP_S+.1, U1.7
TRIM: RV1.2, TP_TRIM.1, U1.6
VIN_24V: F1.1, J_IN.1, TP_VIN.1
VIN_AFTER_F1: F1.2, J_BYP.1, R_LIMIT.1
VIN_TO_MODULE: C_IN.1, C_IN_HF.1, J_BYP.2, R_LIMIT.2, U1.1

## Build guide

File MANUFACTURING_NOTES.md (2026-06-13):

# Manufacturing notes / release gates

## Current release state

Current design state: **v4B engineering candidate**, not yet final fab release.

The repo is now structured for browser review and contains functional PCB architecture for both boards, BOM drafts and production checklist. It is still blocked from a responsible 90-100% manufacturing release by official Mornsun footprint/pinout verification and KiCad DRC/ERC/Gerber export.

## Board build assumptions

- Board size: 50 x 100 mm.
- Layers: 2 copper layers.
- Material: FR-4.
- Copper: 2 oz / 70 um.
- Minimum general clearance target: 0.30 mm.
- Input/output isolation target: 3-5 mm or higher where geometry allows.
- PowerBoard output current: up to 20A at 5V.
- LogicBoard output current: about 0.5A at 12V.

## Fabricator order parameters

- FR-4, 1.6 mm thickness unless enclosure requires otherwise.
- 2-layer PCB.
- 2 oz copper.
- HASL lead-free or ENIG. ENIG preferred for reliability if budget allows.
- Soldermask: any; green is lowest risk.
- Silkscreen: white.
- Minimum drill: check against final DRC after official footprints.
- Electrical test: yes.

## PowerBoard critical notes

- 5V/20A routes must be copper pours/planes, not thin traces.
- Thermal relief must be disabled on high-current connector/module pads.
- Output connector must be rated for real 20A current and selected wire gauge.
- Supercapacitor charging requires controlled inrush. R_LIMIT is a placement strategy, not a final electrical solution until capacitance and pulse energy are known.
- Remote sense must not float. Either wire Sense+/Sense- to load, or close fallback jumpers.
- Trim range must be validated on bench before connecting supercapacitors.
- TVS SMDJ7.0A is placed across 5V/0V near output, but final clamping suitability must be checked against module behavior and load.

## LogicBoard critical notes

- Input and output domains must remain isolated.
- Fan connector must match actual harness polarity.
- Capacitors should be placed close to converter pins.

## Required final validation before ordering

1. Download official Mornsun datasheets and footprints for URF2405QB-100WR3 and URB2412ZP-6WR3.
2. Replace/verify current custom footprints.
3. Run KiCad ERC on real schematic.
4. Run KiCad DRC on PCB with 0.30 mm clearance and 2 oz process constraints.
5. Export Gerber + Excellon drill from KiCad.
6. Open Gerbers in independent viewer.
7. Verify drill holes, board outline, polarity marks, terminal orientation and silkscreen.
8. Perform human EE review before production order.

## Bring-up sequence

PowerBoard:

1. Inspect empty board for shorts between input and output domains.
2. Assemble only connectors, fuse/link, input caps, module, output caps and test points first.
3. Do not connect supercapacitors on first power-up.
4. Power from current-limited bench supply.
5. Verify input current, output voltage, Ctrl behavior, and trim range.
6. Verify Sense fallback jumpers before load test.
7. Load-test gradually: 1A, 5A, 10A, 15A, 20A with thermal monitoring.
8. Only then test precharge into actual supercapacitor bank.

LogicBoard:

1. Power from current-limited 24V source.
2. Verify isolated 12V output without load.
3. Test fan/load current.
4. Verify polarity at all terminals.

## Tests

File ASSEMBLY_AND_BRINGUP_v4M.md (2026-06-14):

# Assembly and bring-up procedure v4M

## Scope

Applies to private-use prototype assembly of LogicBoard and PowerBoard.

## Assembly order

### LogicBoard

1. Inspect bare PCB for shorts and damaged pads.
2. Install U1 URB2412ZP-6WR3 only after footprint orientation check.
3. Install J1, J2, J3.
4. Install C1, C2, C3, C4.
5. Do not connect load yet.
6. Check continuity:
   - J1 pin 1 to U1 pins 22 and 23.
   - J1 pin 2 to U1 pins 2 and 3.
   - U1 pin 14 to J2/J3 pin 1.
   - U1 pin 16 to J2/J3 pin 2.
7. Power from current-limited 24V supply.
8. Verify 12V output at TP3_12V / TP4_0V.
9. Connect fan/load only after unloaded output is stable.

### PowerBoard

1. Inspect bare PCB for shorts and damaged pads.
2. Do not install D_TVS until final TVS/OVP strategy is selected.
3. Do not install RV1 unless trim target and official trim formula are confirmed.
4. Install U1 URF2405QB-100WR3 only after footprint orientation check.
5. Install J_IN, J_OUT, J_CTRL, C_IN, C_IN_HF, C_OUT, C_OUT_HF.
6. Install F1 as fuse or link according to bench plan.
7. Install R_LIMIT only after C_bank / ESR / I_charge calculation.
8. Leave J_BYP open during first power-up.
9. Close JP_S+ and JP_S- if remote sense is not wired.
10. Check continuity:
    - J_IN + to F1 to R_LIMIT path.
    - R_LIMIT output to U1 pin 1.
    - J_IN - to U1 pin 3.
    - U1 pin 8 to J_OUT +.
    - U1 pin 4 to J_OUT 0V.
    - Sense+ fallback to OUT_5V when JP_S+ closed.
    - Sense- fallback to OUT_0V when JP_S- closed.
11. First power-up from current-limited 24V bench supply.
12. J_CTRL open = ON. J_CTRL short to GND_IN = OFF.
13. Verify 5V output at TP_5V / TP_0V with no supercap bank connected.
14. Only after stable unloaded output, test with limited dummy load.
15. Only after dummy-load stability, test precharge into the real capacitive bank.

## No-power conditions

Do not apply power if:

- Any rail is shorted.
- Module orientation is uncertain.
- Sense jumpers are open and remote sense is not wired.
- R_LIMIT is bypassed on first power-up.
- J_BYP is shorted before precharge validation.
- TVS value is guessed rather than selected.
- PowerBoard output connector current rating is unknown.

## Acceptance checks

### LogicBoard

- 24V input present.
- 12V output stable without load.
- Output remains stable with fan/load.
- U1 temperature is acceptable after 15 minutes.

### PowerBoard

- 24V input present.
- 5V output stable without load.
- Ctrl ON/OFF works.
- Sense fallback works.
- Output stable with dummy load.
- Precharge current is within calculated limit.
- No hot connector, no hot copper bottleneck, no module thermal runaway.

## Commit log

2026-06-13 Add PowerBoard viewer placeholder
2026-06-13 Add PowerBoard project file
2026-06-13 Add LogicBoard PCB starter
    [LogicBoard.kicad_pcb]
2026-06-13 Add simplified PowerBoard PCB starter
    [PowerBoard.kicad_pcb]
2026-06-13 Add PowerBoard schematic placeholder
    [PowerBoard.kicad_sch]
2026-06-13 Add LogicBoard schematic placeholder
    [LogicBoard.kicad_sch]
2026-06-13 Add tabbed board viewer index
2026-06-13 Remake LogicBoard PCB to v4A functional layout
    [LogicBoard.kicad_pcb]
2026-06-13 Remake PowerBoard PCB to v4A functional architecture
    [PowerBoard.kicad_pcb]
2026-06-13 Add PowerBoard BOM
    [PowerBoard_BOM.csv]
2026-06-13 Add LogicBoard BOM
    [LogicBoard_BOM.csv]
2026-06-13 Add current project status
2026-06-14 v4C fix LogicBoard to URB ZP DIP24 footprint
    [LogicBoard.kicad_pcb]
2026-06-14 v4C fix PowerBoard URF drills and add required blocks
    [PowerBoard.kicad_pcb]
2026-06-14 Remove temporary connector test file
2026-06-14 v4C update LogicBoard BOM
    [LogicBoard_BOM.csv]
2026-06-14 Add PowerBoard precharge requirements v4D
2026-06-14 Add KiCad DRC rules v4D
2026-06-14 v4E set PowerBoard KiCad net classes
2026-06-14 v4E set LogicBoard KiCad net classes
2026-06-14 v4F generate real LogicBoard schematic from netlist lock
    [LogicBoard.kicad_sch]
2026-06-14 v4F generate real PowerBoard schematic from netlist lock
    [PowerBoard.kicad_sch]
2026-06-14 Update status to v4F schematic generation iteration
2026-06-14 Update index to v4F schematic state
2026-06-14 Add KiCad export script
2026-06-14 Add KiCad CI workflow
2026-06-14 v4K add PowerBoard testpoints mounting holes and silkscreen guards
    [PowerBoard.kicad_pcb]
2026-06-14 v4K add LogicBoard testpoints mounting holes and polarity labels
    [LogicBoard.kicad_pcb]
2026-06-14 v4K extend validator for testpoints and mounting holes
2026-06-14 v4M align PowerBoard BOM with v4K PCB state
    [PowerBoard_BOM.csv]
2026-06-14 v4M align LogicBoard BOM with v4K PCB state
    [LogicBoard_BOM.csv]
2026-06-14 Add v4M BOM audit against original specification
2026-06-14 Add v4M assembly and bring-up procedure
2026-06-14 Update status to v4M BOM and production gate pass
2026-06-14 Update index to v4M BOM and production gate state
